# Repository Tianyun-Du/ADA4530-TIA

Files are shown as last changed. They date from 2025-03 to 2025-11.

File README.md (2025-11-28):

************************************
Author:  Tianyun Du
Date:    March 15 2025
************************************
Discription:
This circuit is designed for precise current measurement.
For me is to measure the intensity of scintillator under X-ray radiation.
The photodiode I used is an HAMAMATSU S1227-1010BR.
The feedback resistance and capacitor used in these two Op Amp are calculated from the online design tool "Photodiode Circuit Design Wizard".
Website: https://tools.analog.com/en/photodiode/
ATTENTION:
IF YOU USE ANOTHER PHOTODIODE, RE-DESIGN THIS CIRCUIT WITH THIS TOOL.
THE PACKAGE OF THESE RESISTANCE AND CAPACITOR ARE "0805".
*************************************

************************************
************POWER SUPPLY************
************************************
USE INTERNAL POWER SUPPLY

The power supply of these Op Amps are ±5V (from 12V), you can also find this design in my other repository.
Use two jumper cap to enable the power supply on board ("H1"&"H2"). You can introduce 12V input from "DC1" OR "P1".

OR....

USE EXTERNAL POWER SUPPLY

External linear power supply can be used for power supply, to obtain a power with lower ripple.
Connect the +5V/AGND/-5V to "P2".
Other voltage can be used like ±10V and ±15V based on the data sheet of ADA4530-1, but I have not test yet.
The website of datasheet:
https://www.analog.com/media/en/technical-documentation/user-guides/ada4530-1r-ebz_ug-865.pdf

*************************************
*********ANOTHER INFORMATION*********
*************************************
DO NOT WELDING THE 0R RESISTANCE IN R2!

DO NOT WELDING THE 0R RESISTANCE IN R2!

DO NOT WELDING THE 0R RESISTANCE IN R2!

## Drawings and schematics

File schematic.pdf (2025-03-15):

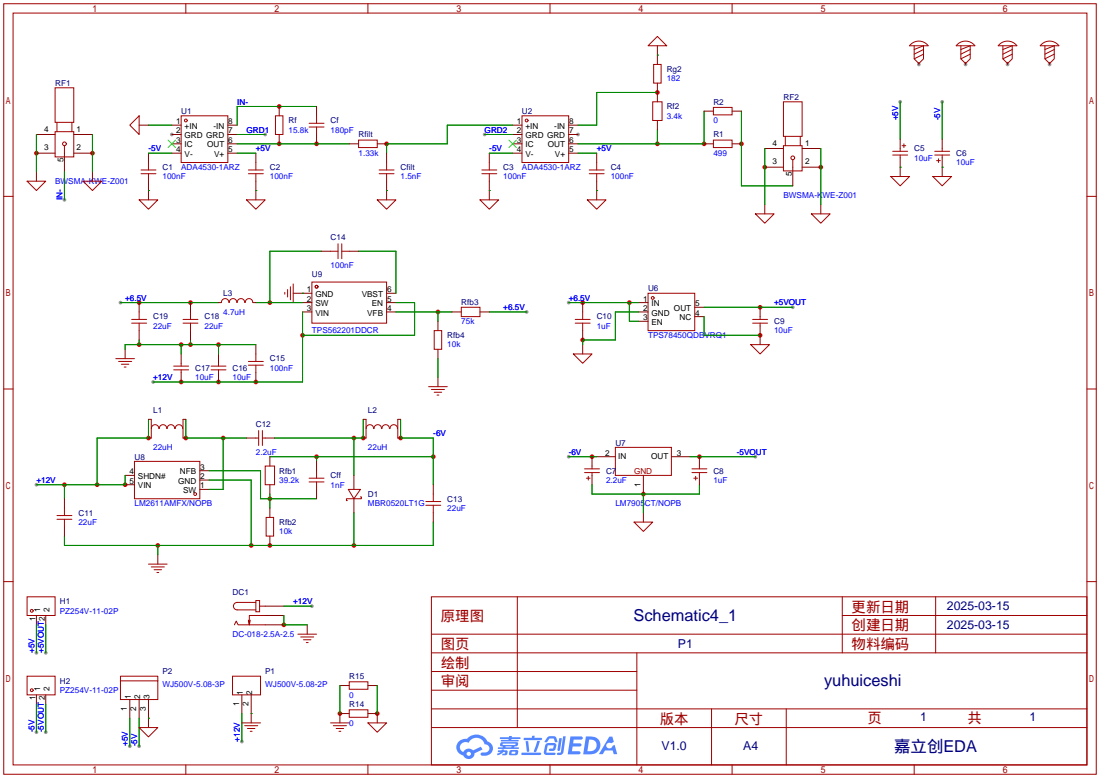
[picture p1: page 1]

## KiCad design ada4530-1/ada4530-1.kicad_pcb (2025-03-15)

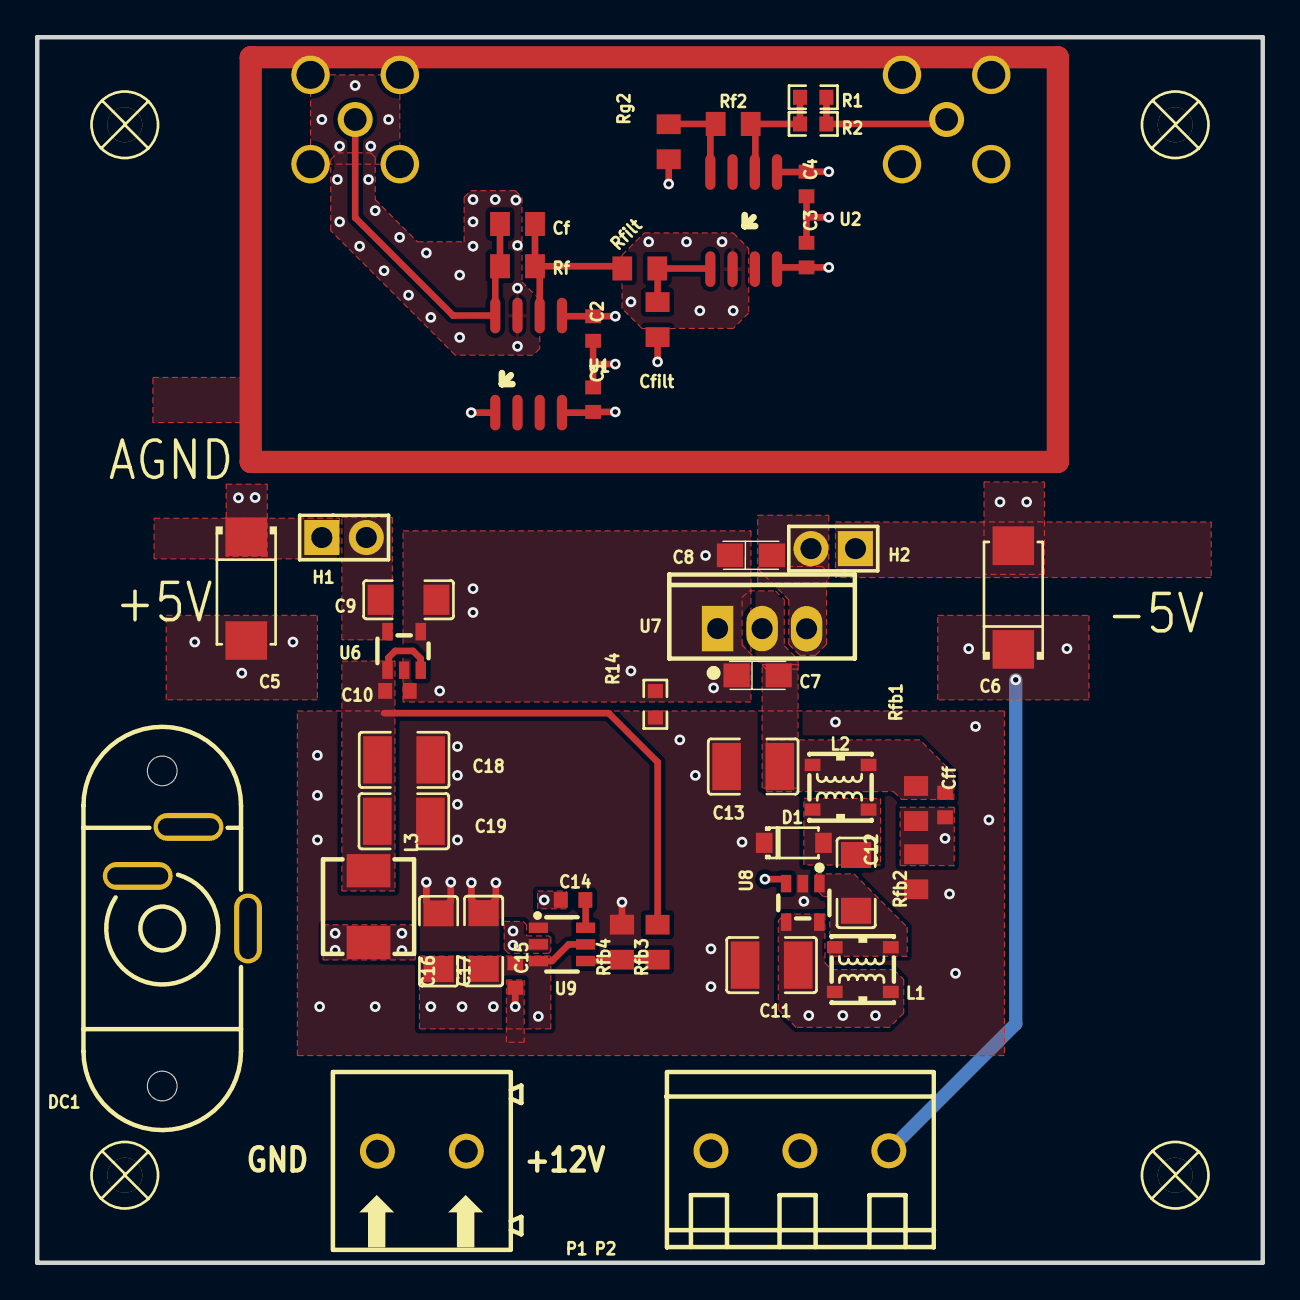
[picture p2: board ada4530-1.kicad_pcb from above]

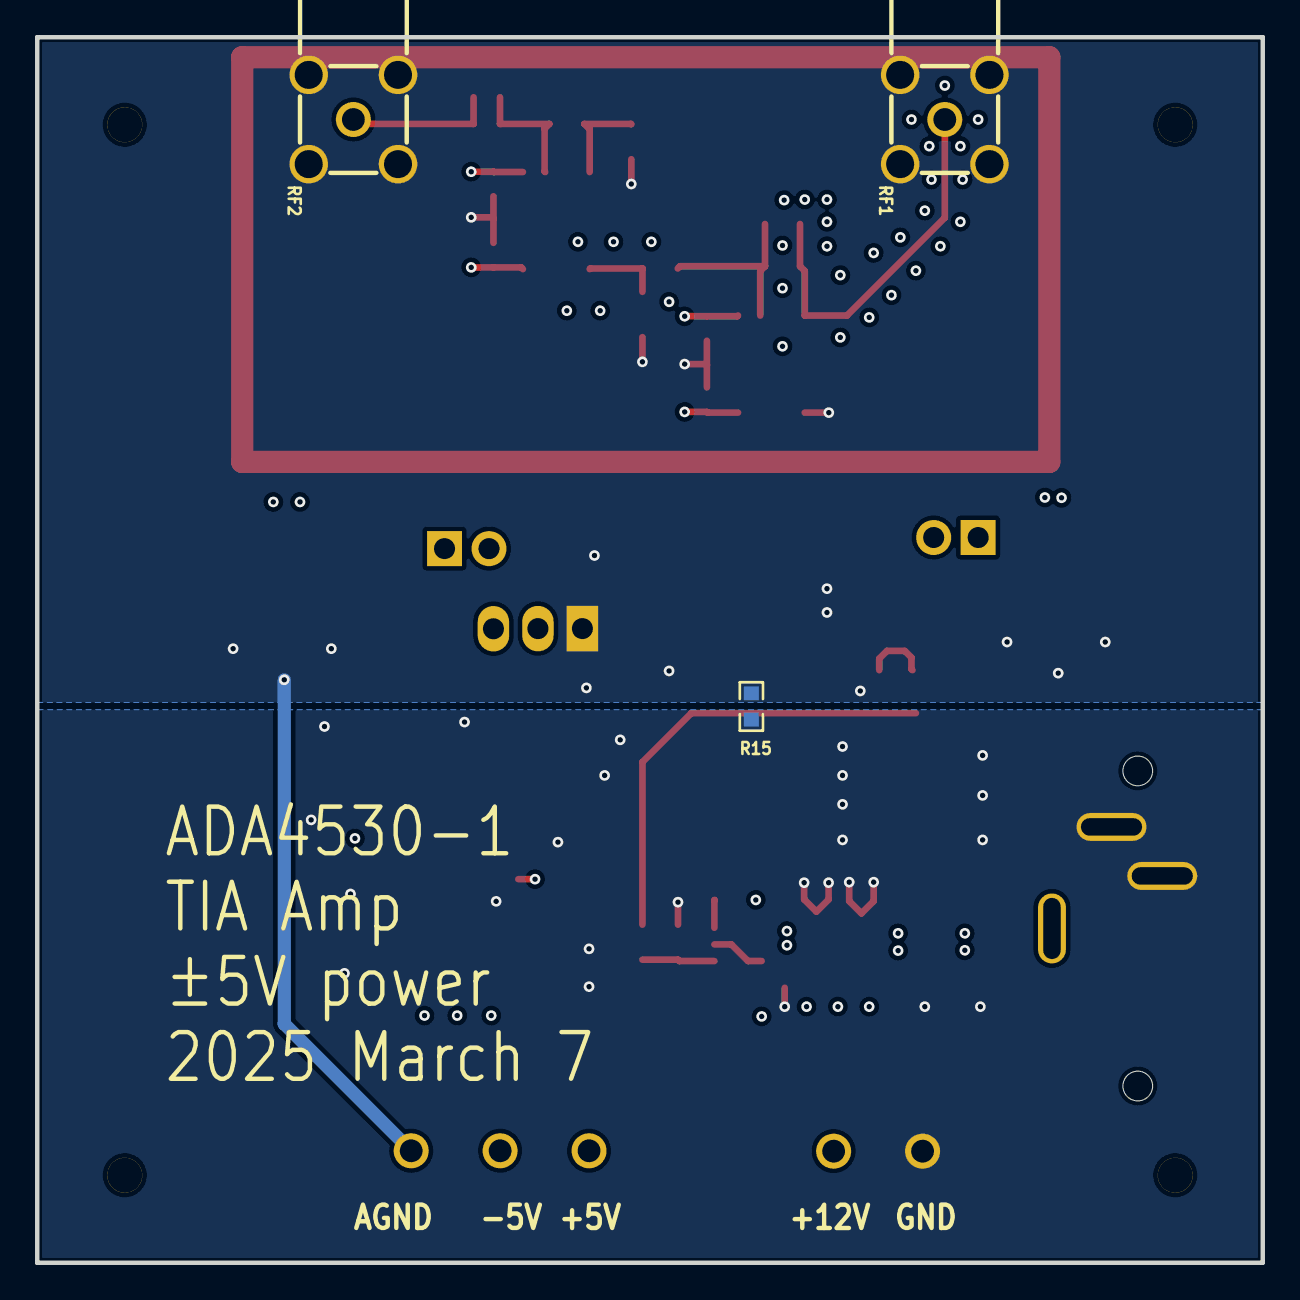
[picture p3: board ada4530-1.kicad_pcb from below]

Board: 4 copper layers, 70.0 x 70.0 mm, 55 parts (3 on the bottom side), 21 nets.

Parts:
C1, C2, C3, C4, C10, C14, C15: C0603
C5, C6: CAP-SMD_L6.0-W3.2-R-RD
C7, C8: CASE-A_3216
C9, C12, C16, C17: C1206
C11, C13, C18, C19: C1210
Cf: R0805
Cff: C0603
Cfilt: R0805
D1: SOD-123_L2.8-W1.8-LS3.7-RD
DC1: DC-IN-TH_DC-018
H1, H2: HDR-TH_2P-P2.54-V-M
L1, L2: IND-SMD_4P-L3.8-W3.5_BL
L3: IND-SMD_L5.4-W5.2_FXL0530
P1: CONN-TH_2P-P5.00_WJ500V-5.08-2P
P2: CONN-TH_3P-P5.00_WJ500V-5.08-3P
R1, R2, R14, R15: R0603
RF1, RF2: SMA-TH_BWSMA-KWE-Z001
Rf, Rf2: R0805
Rfb1, Rfb2, Rfb3, Rfb4: R0805
Rfilt: R0805
Rg2: R0805
SCREW1, SCREW2, SCREW3, SCREW4: M2螺丝
U1, U2: SOIC-8_L4.9-W3.9-P1.27-LS6.0-BL
U6: SOT-23-5_L2.9-W1.6-P0.95-LS2.8-BL
U7: TO-220-3_L10.0-W4.5-P2.54-L
U8: SOT-23-5_L2.9-W1.6-P0.95-LS2.8-BR
U9: SOT-23-6_L2.9-W1.6-P0.95-LS2.8-BR

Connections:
$1N1239: Cf.1, Rf.1, Rfilt.2, U1.6
$1N1441: Cfilt.2, Rfilt.1, U2.1
$1N1504: R1.1, R2.2, Rf2.1, U2.6
$1N1510: Rf2.2, Rg2.1, U2.8
$1N1693: R1.2, R2.1, RF2.5
$1N3691: C12.1, L1.2, L1.3, U8.1
$1N3697: Cff.1, Rfb1.1, Rfb2.2, U8.3
$1N3853: C12.2, D1.2, L2.1, L2.4
$1N5017: C14.2, L3.2, U9.2
$1N5032: C14.1, U9.6
$1N5055: Rfb3.1, Rfb4.2, U9.4
+5V: C2.2, C4.2, C5.1, H1.1, P2.1, U1.5, U2.5
+5VOUT: C9.2, H1.2, U6.5
+6.5V: C10.2, C18.2, C19.2, L3.1, Rfb3.2, U6.1, U6.3
+12V: C11.2, C15.2, C16.1, C17.1, DC1.1, L1.1, L1.4, P1.1, U8.4, U8.5, U9.3, U9.5
-5V: C1.2, C3.1, C6.2, H2.1, P2.2, U1.4, U2.4
-5VOUT: C8.2, H2.2, U7.3
-6V: C7.2, C13.2, Cff.2, L2.2, L2.3, Rfb1.2, U7.2
AGND: C1.1, C2.1, C3.2, C4.1, C5.2, C6.1, C7.1, C8.1, C9.1, C10.1, Cfilt.1, P2.3, R14.1, R15.1, RF1.1, RF1.2, RF1.3, RF1.4, RF2.1, RF2.2, RF2.3, RF2.4, Rg2.2, U1.1, U6.2, U6.4, U7.1
GND: C11.1, C13.1, C15.1, C16.2, C17.2, C18.1, C19.1, D1.1, DC1.2, DC1.3, P1.2, R14.2, R15.2, Rfb2.1, Rfb4.1, U8.2, U9.1
IN-: Cf.2, RF1.5, Rf.2, U1.8
